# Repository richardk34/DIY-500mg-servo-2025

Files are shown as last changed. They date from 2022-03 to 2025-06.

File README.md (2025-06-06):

# DIY-500mg-servo
500mg Servo for a micro RC model.
Forked from a fork of Charles Maulion's 500mg Servo Project on rcgroups.com

Currently developing a new version of the servo main body to work with my combination of motor and carbon fiber shafts.
Circuit boards are ordered and were soldered.

The plan is to use cycloidal gears derived from watchmaking standards to reduce the amount of friction that standard involute gears result in. 

More about gears:
https://www.numericana.com/answer/gears.htm#horology

https://www.hessmer.org/gears/CycloidalGearBuilder.html

https://hessmer.org/gears/CycloidalGearBuilder.html







The electronic board components are as follows:

3 components :
1 atmel attiny1616 / 416 in  20-pin VQFN 3x3 mm
1 hall linear sensor : 49E-sot23 or A1304-sot23
1 cap 


To program Attiny1616 with one wire UDPI, you need to made UDPI programmer : (use arduino 3.3V)
https://create.arduino.cc/projecthub/john-bradnam/create-your-own-updi-programmer-1e55f1

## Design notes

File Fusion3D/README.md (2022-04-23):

# Fusion3D
Slightly reworked Fusion360 files and STL files for servo parts.

## Fusion360 Files
* Cybermike_500mg-Servo_assembly - An exported Fusion360 archive file containing the original parts as well as my modifications.  The most interesting components are:
  * Cybermike MotorSupport:1 - this is where most of the changes are
  * Regenerated worm gear - deeper teeth:1 - this is the regenerated worm gear with deeper cut teeth

## PC Board Files
- EAGLE - Modified PCB files for (hopefully) easier soldering

## STL Files
- Base - Base and top plate files
- Worm - Regenerated worm gear that seems to mate better with certain resins
- Gears - Spur and output gears with different bore sizes
- ProgrammingAdapter - a 3D printable programming adapter using spring loaded pogo pins that mate with the modified PCBs

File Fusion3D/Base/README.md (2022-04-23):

# Base

Base and top plates with gear spacing and bore sizes testing with different resins

File name encodes the spacing and bore size, e.g., "L3_450_S800" means 3.450mm gear spacing and 8.0mm bore, "L3_500_835" means 3.500mm gear spacing with 8.35mm bore, etc.

- Base_Flat_*.stl - Base for flat-can cored motor (from Aliexpress, etc.) with no mounting bosses
- Base_FlatBoss_*.stl - Base for flat-can cored motor with carbon fiber rod mounting bosses
- TopPlate_*.stl - Top plate

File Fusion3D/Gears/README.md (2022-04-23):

# Gears

Gears with different bore sizes for testing with different resins

File name encodes the bore size, e.g., "S899" means 0.899mm shaft bore.

- OutputNoArm - a full circle output gear with the same height as the
  normal output gear to use for testing sensors and magent positions
- ShortSpur - The intermediate spur gear
- TallSpur - The first stage spur gear that meshes with the worm

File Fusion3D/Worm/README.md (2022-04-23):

# Worm
Worm gear STL files with deeper teeth and different sized bores.  These
are generated with a deeper tooth profile to make up for the slightly
thicker Siraya Tech Mecha and Elegoo White water washable resin print.

I recommend printing the worm gear at 0.25um (or smaller) layer height for best detail.

The Worm_Set.* files contain 3 sets of all 10 bore sizes for calibrating
against your printer.

The .pwma files are my slice for an Anycubic Photon Mono 4K with Elegoo white
water washable resin and Siraya Tech Mecha at a 0.025mm layer height.

The worm gear was regenerated using the HelicalGearPlus Fusion360 plug-in.

These settings match the original from maulionc pretty well:

Setting         | Value
-------         | -----
Type            | External Gear
Module          | 0.20 mm
Helix Angle     | 85.0 deg
Teeth           | 1
Gear width      | 3.0mm
Standard Normal |
Pressure angle  | 20 deg
Backlash        | 1.0mm
Addendum        | 1.6
Dedendum        | 0.65

For a deeper tooth profile that worked better, I used these settings:
Setting         | Value
-------         | -----
Backlash        | 0mm
Addendum        | 1.7
Dedendum        | 1.25

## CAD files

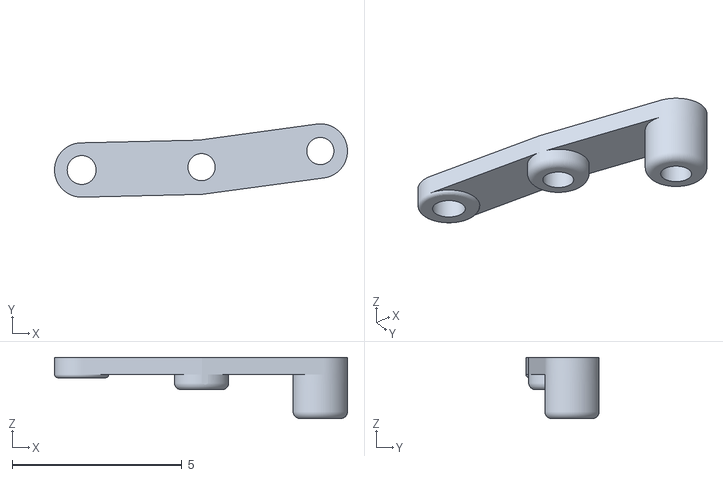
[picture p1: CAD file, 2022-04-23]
Fusion3D/Base/TopPlate_L3_535_S800.stl
8.63 x 2.16 x 1.80

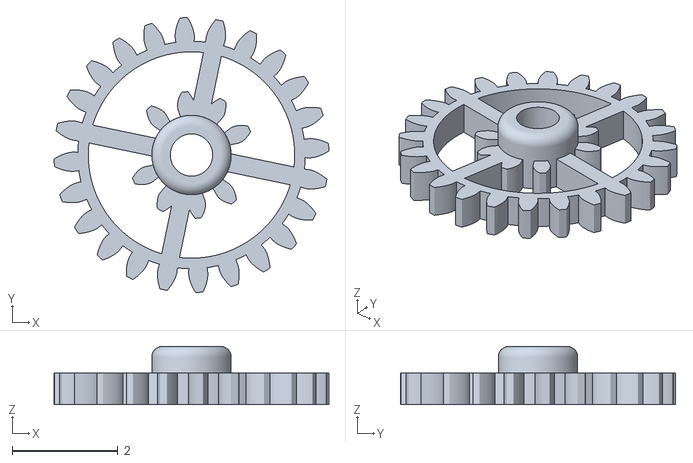
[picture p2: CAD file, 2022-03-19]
Fusion3D/Gears/OutputNoArm/OutputNoArm_S8.stl
5.20 x 5.20 x 1.10

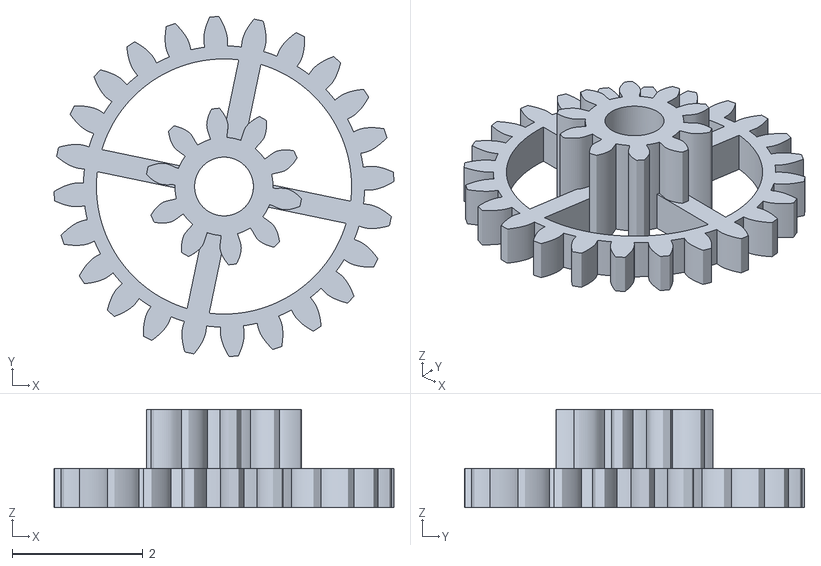
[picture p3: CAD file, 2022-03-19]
Fusion3D/Gears/ShortSpur/ShortSpur-S899.stl
5.20 x 5.20 x 1.50

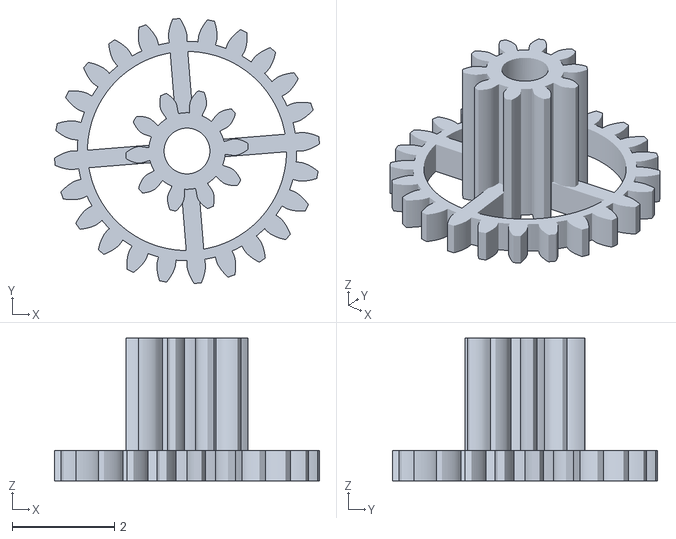
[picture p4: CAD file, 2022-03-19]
Fusion3D/Gears/TallSpur/TallSpur-S899.stl
5.19 x 5.19 x 2.80

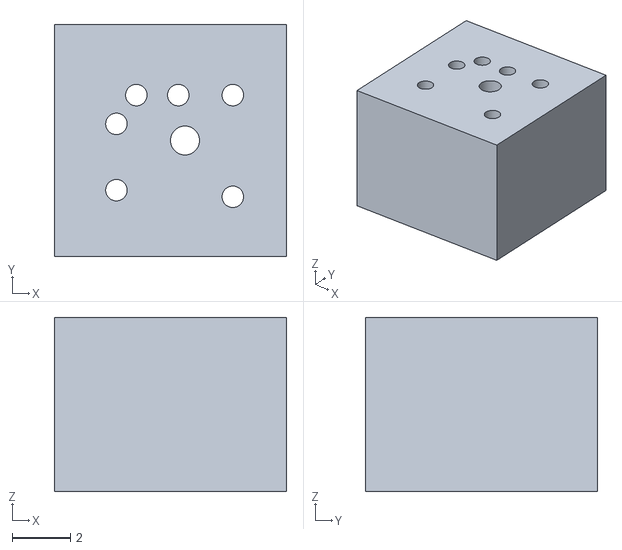
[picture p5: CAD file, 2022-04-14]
Fusion3D/ProgrammingAdapter/ProgrammingAdapter.stl
8.00 x 8.00 x 6.00

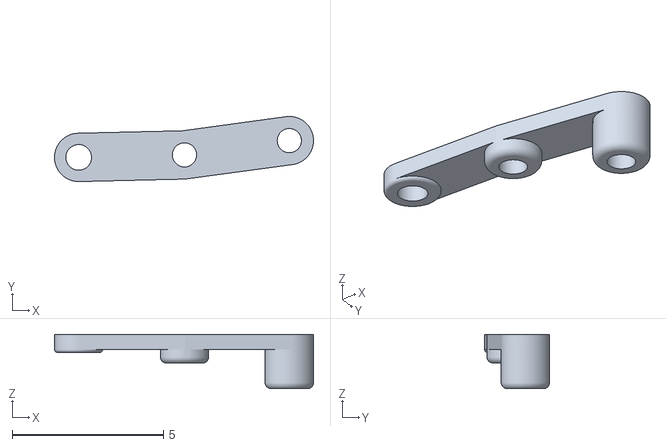
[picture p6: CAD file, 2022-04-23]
Fusion3D/Base/TopPlate_L3_500_S800.stl
8.57 x 2.15 x 1.80

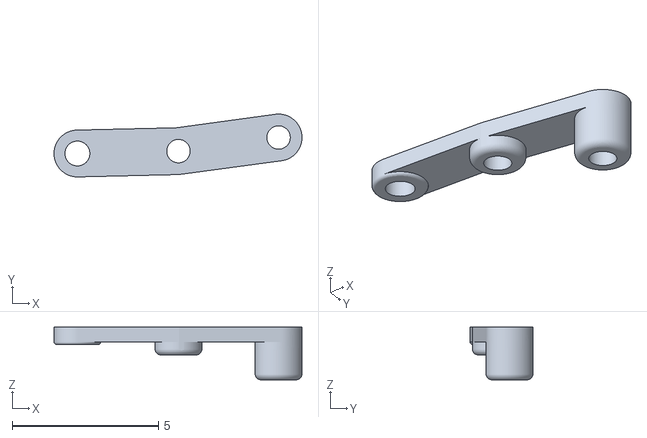
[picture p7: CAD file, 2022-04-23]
Fusion3D/Base/TopPlate_L3_450_S800.stl
8.47 x 2.15 x 1.80

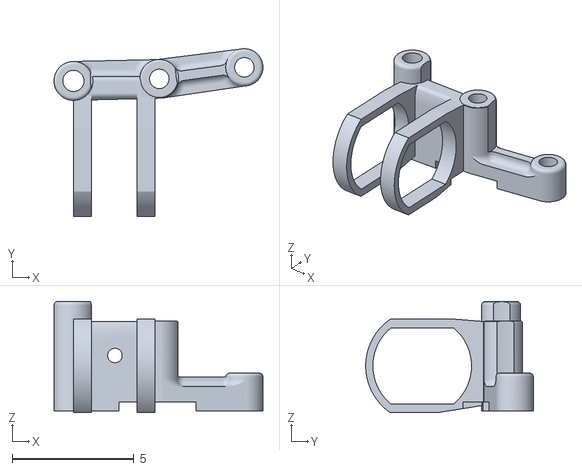
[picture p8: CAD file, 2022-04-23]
Fusion3D/Base/Base_Flat_L3_535_S800.stl
8.59 x 6.89 x 4.57

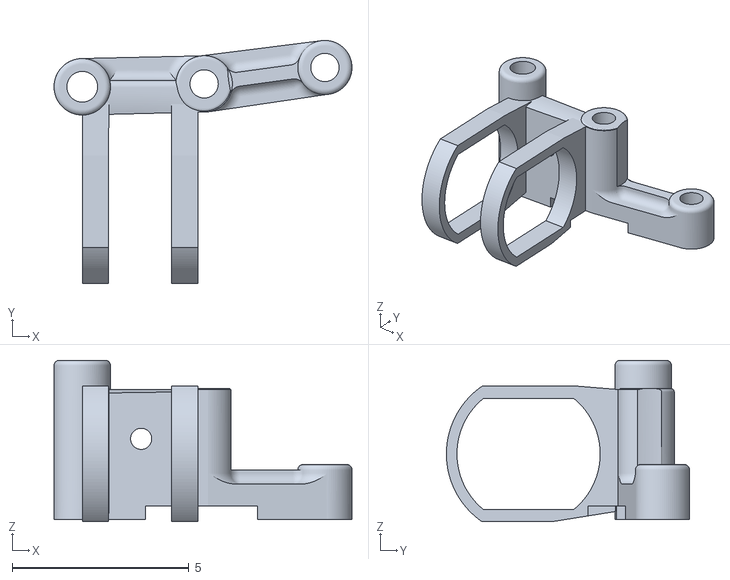
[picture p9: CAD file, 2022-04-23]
Fusion3D/Base/Base_Flat_L3_450_S800.stl
8.44 x 6.88 x 4.57

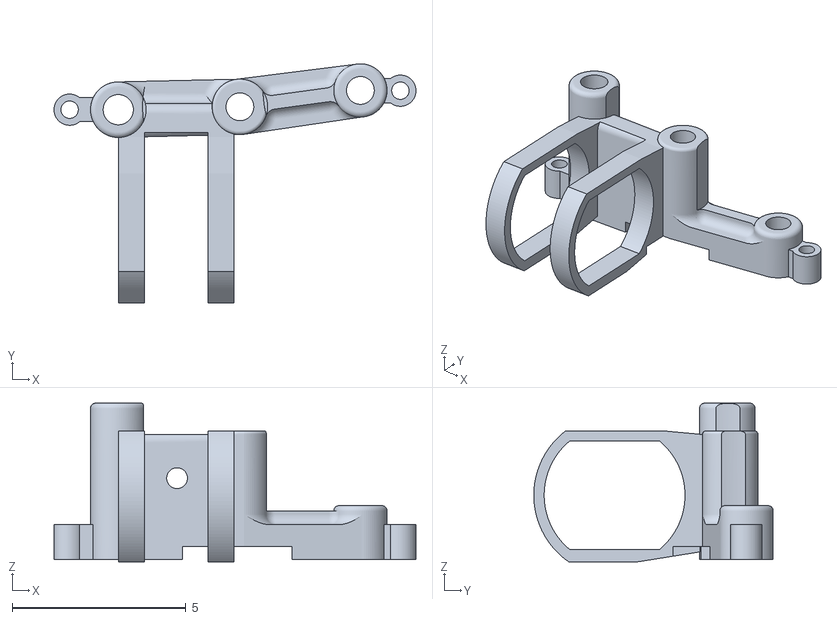
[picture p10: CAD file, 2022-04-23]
Fusion3D/Base/Base_FlatBoss_L3_500_S800.stl
10.4 x 6.89 x 4.57

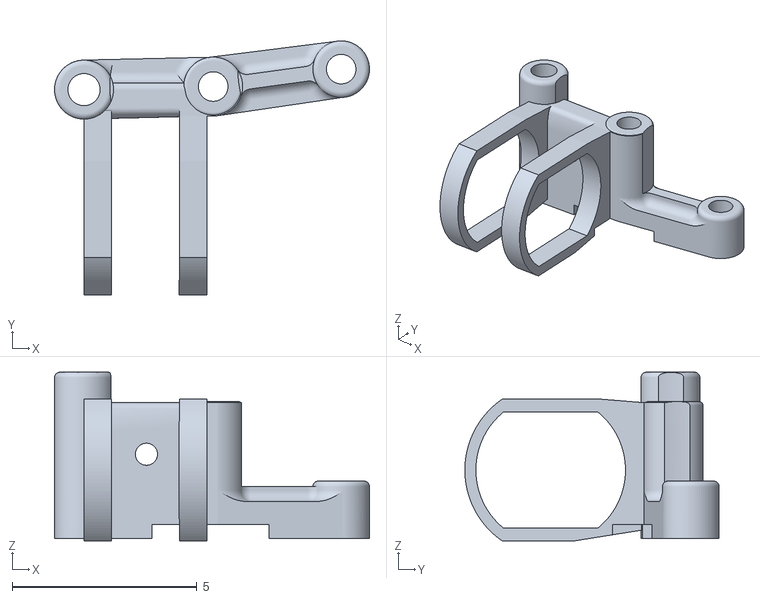
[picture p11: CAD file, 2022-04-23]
Fusion3D/Base/Base_Flat_L3_500_S800.stl
8.53 x 6.89 x 4.57

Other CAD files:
Fusion3D/Base/Base_FlatBoss_L3_450_S800.stl
Fusion3D/Base/Base_Flat_L3_450_S835.stl
Fusion3D/Base/TopPlate_L3_535_S899.stl
Fusion3D/Base/Base_Flat_L3_535_S835.stl
Fusion3D/Base/TopPlate_L3_450_S899.stl
Fusion3D/Base/Base_Flat_L3_500_S835.stl
Fusion3D/Base/TopPlate_L3_500_S899.stl

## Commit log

2022-02-25 Added Fusion3D file with tweaks and STL with solid worm gear
2022-03-01 Added new worm gear profile
2022-03-01 Added worm gears with different bores
2022-03-01 Added STL with set of all gears
2022-03-01 Added Photon Mono X 4K slice of Worm_Set.stl
2022-03-01 Add new worm gear profile and bores (#2)
    * Added new worm gear profile
    * Added worm gears with different bores
    * Added STL with set of all gears
    * Added Photon Mono X 4K slice of Worm_Set.stl
    * Modified text
2022-03-14 Added new gears
    [OutputNoArm_S8.stl, ShortSpur-S899.stl, TallSpur-S899.stl]
2022-04-14 Notch for circuit board and original gear spacing
    [Base_Flat_L3_450_S835.stl, Base_Flat_L3_500_S835.stl, Base_Flat_L3_535_S835.stl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]
2022-04-14 Minor updates
    [Base_Flat_L3_450_S835.stl]
2022-04-23 Added Base parts with boss, new spacing/bore sizes and PCB files
    [Base_FlatBoss_L3_450_S800.stl, Base_FlatBoss_L3_500_S800.stl, Base_Flat_L3_450_S800.stl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]
